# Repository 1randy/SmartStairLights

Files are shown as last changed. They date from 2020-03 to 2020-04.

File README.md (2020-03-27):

# Smart Stair Lights

A ESP / Arduino based Automatic Stair Liights with WS2801 LED Driver Board.

:warning: **Use at your own risk, always check your layout before manufacturing!**

## Features

 - support for Infrared, PIR, Mechanical Sensors
 - cascadable WS2801 Board
 - Dimmed LEDs when inactive

## Planned Features

 - MQTT Support for remote activating

## Schematic

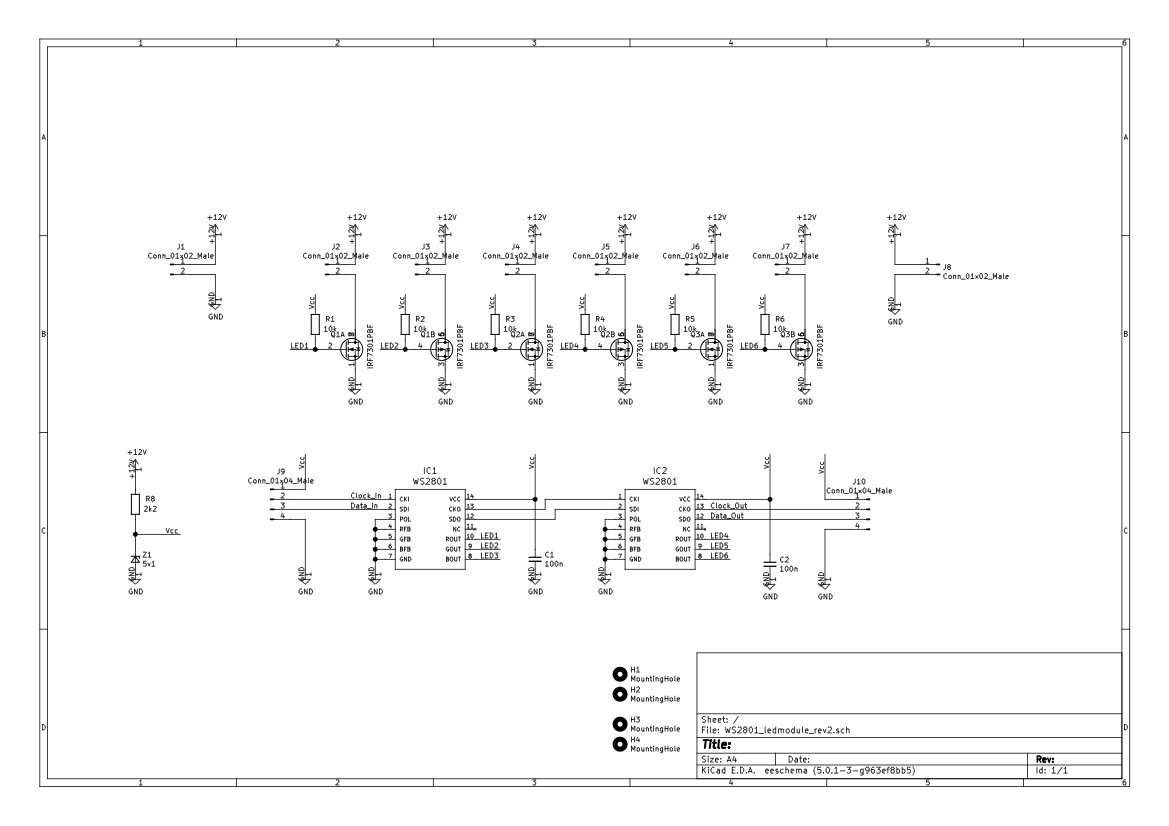
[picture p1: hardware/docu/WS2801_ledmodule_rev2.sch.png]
schematic
<br>
[PDF download](https://raw.githubusercontent.com/1randy/SmartStairLights/master/hardware/docu/WS2801_ledmodule_rev2.sch.pdf)

## Board

**Top side**

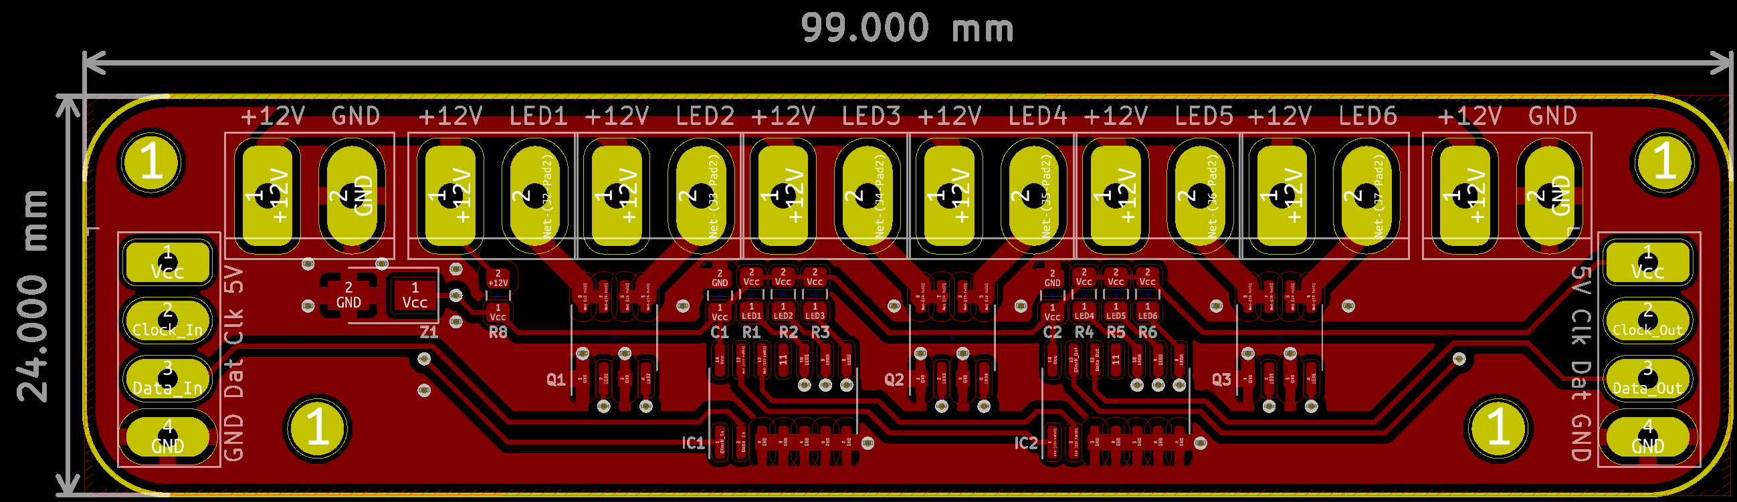
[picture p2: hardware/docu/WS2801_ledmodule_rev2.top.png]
PCB TOP
    

You can order the PCB of this board at [elecrow][1] with the supplied gerbers.

## Links

[1]: https://www.elecrow.com/pcb-manufacturing.html

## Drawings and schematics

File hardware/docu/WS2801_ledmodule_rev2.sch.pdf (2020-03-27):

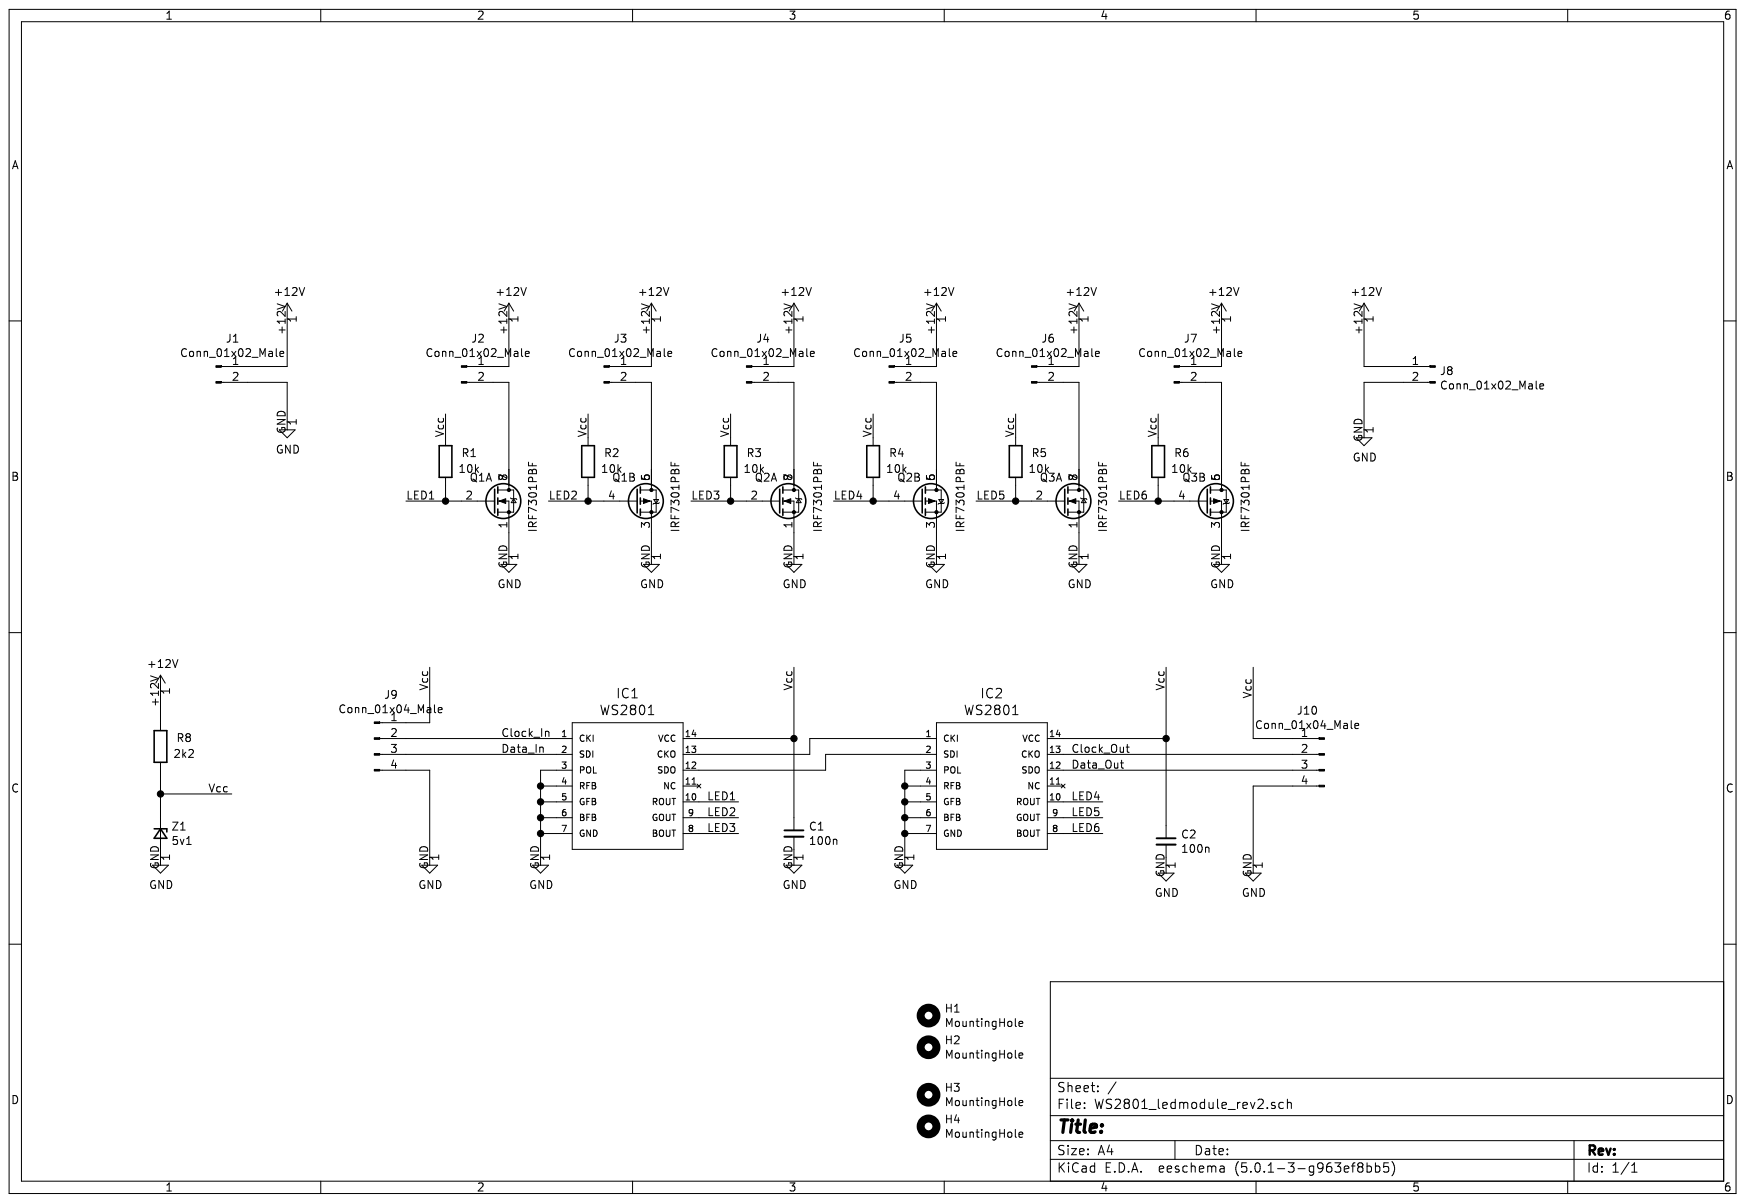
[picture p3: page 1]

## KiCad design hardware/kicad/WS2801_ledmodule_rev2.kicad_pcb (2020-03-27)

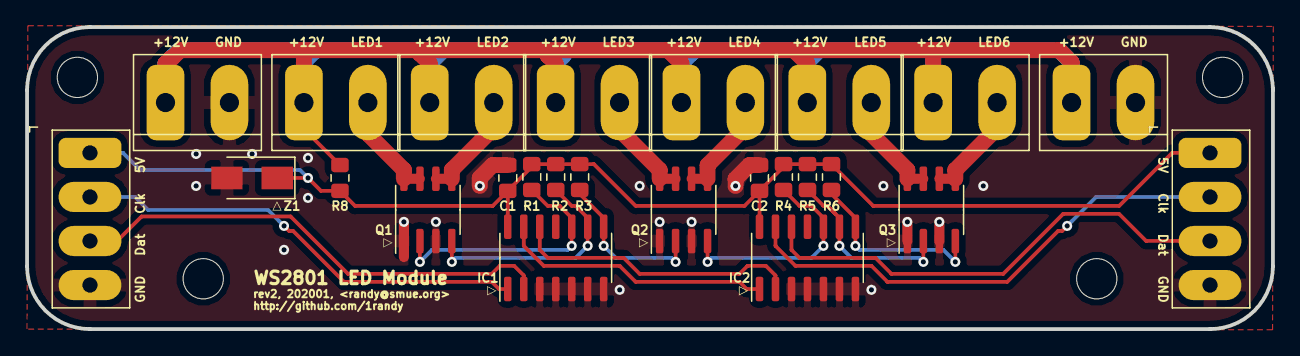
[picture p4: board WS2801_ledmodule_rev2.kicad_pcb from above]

Board: 2 copper layers, 99.0 x 24.0 mm, 28 parts (0 on the bottom side), 21 nets.

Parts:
5V   Clk   Dat   GND: Conn_01x04_Male; TerminalBlock_Phoenix_PT-1,5-4-3.5-H_1x04_P3.50mm_Horizontal
+12V    GND, +12V    GND#2, +12V    LED1, +12V    LED2, +12V    LED3, +12V    LED4, +12V    LED5, +12V    LED6: Conn_01x02_Male; TerminalBlock_bornier-2_P5.08mm
C1, C2: 100n; C_0805_2012Metric_Pad1.15x1.40mm_HandSolder
GND   Dat   Clk   5V: Conn_01x04_Male; TerminalBlock_Phoenix_PT-1,5-4-3.5-H_1x04_P3.50mm_Horizontal
H2, H3, H4: MountingHole; MountingHole_3.2mm_M3
IC1, IC2: WS2801; SOIC-14_3.9x8.7mm_P1.27mm
Q1, Q2, Q3: IRF7301PBF; SOIC-8_3.9x4.9mm_P1.27mm
R1, R2, R3, R4, R5, R6: 10k; R_0805_2012Metric_Pad1.15x1.40mm_HandSolder
R8: 2k2; R_0805_2012Metric_Pad1.15x1.40mm_HandSolder
Z1: 5v1; D_SMA

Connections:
+12V: +12V GND.1, +12V GND#2.1, +12V LED1.1, +12V LED2.1, +12V LED3.1, +12V LED4.1, +12V LED5.1, +12V LED6.1, R8.2
/Clock_In: GND Dat Clk 5V.2, IC1.1
/Clock_Out: 5V Clk Dat GND.2, IC2.13
/Data_In: GND Dat Clk 5V.3, IC1.2
/Data_Out: 5V Clk Dat GND.3, IC2.12
/LED1: IC1.10, Q1.2, R1.1
/LED2: IC1.9, Q1.4, R2.1
/LED3: IC1.8, Q2.2, R3.1
/LED4: IC2.10, Q2.4, R4.1
/LED5: IC2.9, Q3.2, R5.1
/LED6: IC2.8, Q3.4, R6.1
/Vcc: 5V Clk Dat GND.1, C1.1, C2.1, GND Dat Clk 5V.1, IC1.14, IC2.14, R1.2, R2.2, R3.2, R4.2, R5.2, R6.2, R8.1, Z1.1
GND: 5V Clk Dat GND.4, +12V GND.2, +12V GND#2.2, C1.2, C2.2, GND Dat Clk 5V.4, IC1.3, IC1.4, IC1.5, IC1.6, IC1.7, IC2.3, IC2.4, IC2.5, IC2.6, IC2.7, Q1.1, Q1.3, Q2.1, Q2.3, Q3.1, Q3.3, Z1.2
unnamed: IC1.12, IC2.2
unnamed: IC1.13, IC2.1
unnamed: +12V LED1.2, Q1.7, Q1.8
unnamed: +12V LED2.2, Q1.5, Q1.6
unnamed: +12V LED3.2, Q2.7, Q2.8
unnamed: +12V LED4.2, Q2.5, Q2.6
unnamed: +12V LED5.2, Q3.7, Q3.8
unnamed: +12V LED6.2, Q3.5, Q3.6

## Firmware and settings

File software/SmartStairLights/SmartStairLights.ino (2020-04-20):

#include <FastLED.h>

#define VERSION 2020042001

// define sendor input pins
#define INPUT_PIN_1_PULLUP      // enable pullup for switche (not needed for PIR/IR)
#define INPUT_PIN_2_PULLUP      // enable pullup for switche (not needed for PIR/IR)
#define INPUT_PIN_1     A0      // 18 A0
#define INPUT_PIN_2     A1      // 19 A1


// Setup LED connection
#define DATA_PIN        2
#define CLOCK_PIN       3
#define NUM_LEDS        6       // count of all LED ports
#define CHIPSET         WS2801
#define COLOR_ORDER     RGB

#define BRIGHTNESS_MIN  10      // dim level for inactivity
#define BRIGHTNESS_MAX  255     // max brightness of the LED Stripes

#define WAIT            1000    // wait time after a sequence in ms
#define WAIT_PIN_READ   250     // time between input status query in ms
#define WAIT_PIN_MAXW   100     // timeout of second timer event in ms = WAIT_PIN_READ * WAIT_PIN_MAXW(ait)

#define FADE_WAIT       2       // speed of LED dimming
#define FADE_STEP       20      // steps of LED brightness levels

#define SENSOR_WAIT     5000    // how long the pir sensor should be blocked
CRGB leds[NUM_LEDS];

void setup() {
    delay( 3000 ); // power-up safety delay

    pinMode(INPUT_PIN_1, INPUT);           // set pin to input
    pinMode(INPUT_PIN_2, INPUT);           // set pin to input
#ifdef INPUT_PIN_1_PULLUP
    digitalWrite(INPUT_PIN_1, HIGH);       // turn on pullup resistors
#endif
#ifdef INPUT_PIN_2_PULLUP
    digitalWrite(INPUT_PIN_2, HIGH);       // turn on pullup resistors
#endif

    FastLED.addLeds<CHIPSET, DATA_PIN, CLOCK_PIN, COLOR_ORDER>(leds, NUM_LEDS).setCorrection( TypicalLEDStrip );

    // LED check
    FadeSequenceForward(1); 
    FadeSequenceBackward(0);

    Serial.println("setup done.");
}

void FadeUp(int lednum, int color) {
  for ( int brightness = BRIGHTNESS_MIN; brightness < BRIGHTNESS_MAX; brightness=brightness+FADE_STEP) {
    leds[lednum][color] = brightness;
    FastLED.show();
    delay(FADE_WAIT + 2);
  } 
  leds[lednum][color] = BRIGHTNESS_MAX;
  FastLED.show();
}


void FadeDown(int lednum, int color) {
  for ( int brightness = BRIGHTNESS_MAX; brightness > BRIGHTNESS_MIN; brightness=brightness-FADE_STEP ) {
    leds[lednum][color] = brightness;
    FastLED.show();
    delay(FADE_WAIT + 2);
  } 
  leds[lednum][color] = BRIGHTNESS_MIN;
  FastLED.show();
}

void FadeSequenceForward(bool led_on) {
  Serial.println("FadeSequenceForward()");
  for ( int out = 0; out < NUM_LEDS-1; out++ ) {
    for ( int color = 0; color < 3; color++ ) {
      if (led_on) {
        FadeUp(out, color);
      }  else {
        FadeDown(out,color);
      }
    }
  }
  delay(WAIT);
}

void FadeSequenceBackward(bool led_on) {
  Serial.println("FadeSequenceBackward()");
  for ( int out = NUM_LEDS-1; out >= 0; out-- ) {
    for ( int color = 2; color >= 0; color-- ) {
      if (led_on) {
        FadeUp(out, color);
      }  else {
        FadeDown(out,color);
      }
    }
  }
  delay(WAIT);
}

bool readInput1() {
#ifdef INPUT_PIN_1_PULLUP
  return (!digitalRead(INPUT_PIN_1));
#else
  return (digitalRead(INPUT_PIN_1));
#endif
}

bool readInput2() {
#ifdef INPUT_PIN_2_PULLUP
  return (!digitalRead(INPUT_PIN_2));
#else
  return (digitalRead(INPUT_PIN_2);
#endif
}
void loop()
{
  uint16_t wait_timout = 0;

// forward sequence 1 -> MAX_LED
  if (readInput1()) {
    Serial.println("start sequence on event1");
    FadeSequenceForward(1);
    while(!readInput2() && wait_timout < WAIT_PIN_MAXW) {
      if (readInput1()) {
        wait_timout = 0;
      } else {
        wait_timout++;
      }
      delay(WAIT_PIN_READ);
    }
    Serial.println("stop sequence on event2");
    FadeSequenceForward(0);
    delay(SENSOR_WAIT);
  }
  
  // backward sequence MAX_LED -> 1
  if (readInput2()) {
    Serial.println("start sequence on event2");
    FadeSequenceBackward(1);
    while(!readInput1() && wait_timout < WAIT_PIN_MAXW) {
      if (readInput2()) {
        wait_timout = 0;
      } else {
        wait_timout++;
      }
      delay(WAIT_PIN_READ);
    }
    Serial.println("stop sequence on event1");
    FadeSequenceBackward(0);
    delay(SENSOR_WAIT);
  }
} // END main loop

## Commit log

2020-03-27 initial upload
    [WS2801_ledmodule_rev2-B.Cu.gbr, WS2801_ledmodule_rev2-B.Mask.gbr, WS2801_ledmodule_rev2-B.Paste.gbr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]
2020-04-20 make pullups switchable (PIR sensor support)
